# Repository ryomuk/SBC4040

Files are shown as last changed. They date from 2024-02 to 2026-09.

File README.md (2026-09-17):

# SBC4040
Single Board Computer using Intel 4040

This document is written mostly in Japanese.
If necessary, please use a translation service such as DeepL (I recommend this) or Google.

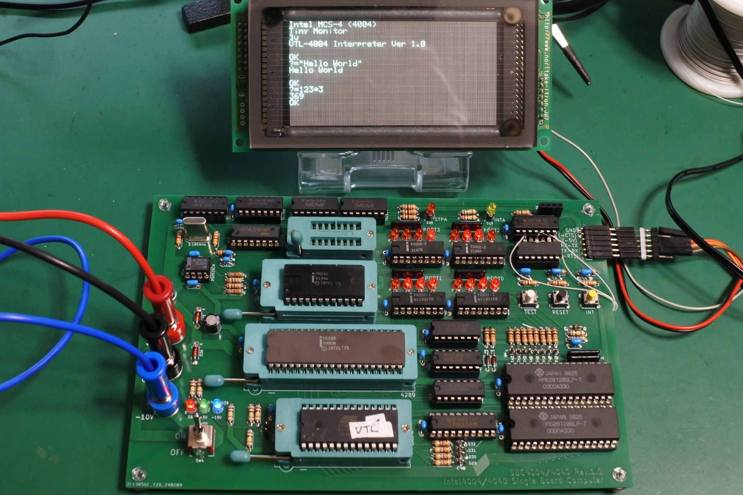
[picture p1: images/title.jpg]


## 概要
CPUにIntel 4040を採用したシングルボードコンピュータです．4004実験用ボードをベースにして作りました．4004版と完全上位互換なはず．4040の代わりに4004も載せられるようにしてあります．(絶対に同時には搭載しないこと!)

4040にすることによって追加された機能は下記の通りです．

- ROM領域が4KBから8KBに増加
- サブルーチンコールが3段から7段に増加
- PMR命令により，プログラム領域のRAMを直接読めるようになったはず(未確認)
- 割り込み機能
- ステップ実行は使い道が無さそうなので端子だけ出して未実装

## ToDo
- 割り込み機能の動作確認
- 拡張ROM領域(CMROM1)の動作確認
- PMR命令の動作確認
- モニタプログラム，VTL, 8080エミュレータ等を4040用にリライト

## ブログ
関連する情報が書いてあるかも．
- [Intel 4004関連記事のまとめ](https://note.com/ryomuk/m/m2f55e2a1f586)

## 動画
Youtubeで関連動画を公開しています．
- https://www.youtube.com/@ryomukai/videos

## 参考にした文献，サイト
### データシート
- http://www.bitsavers.org/components/intel/
- https://www.intel-vintage.info/intelmcs.htm

### ソフトウェア開発環境
- [The Macroassembler AS](http://john.ccac.rwth-aachen.de:8000/as/)

## 更新履歴
- 2024/2/22: 初版公開

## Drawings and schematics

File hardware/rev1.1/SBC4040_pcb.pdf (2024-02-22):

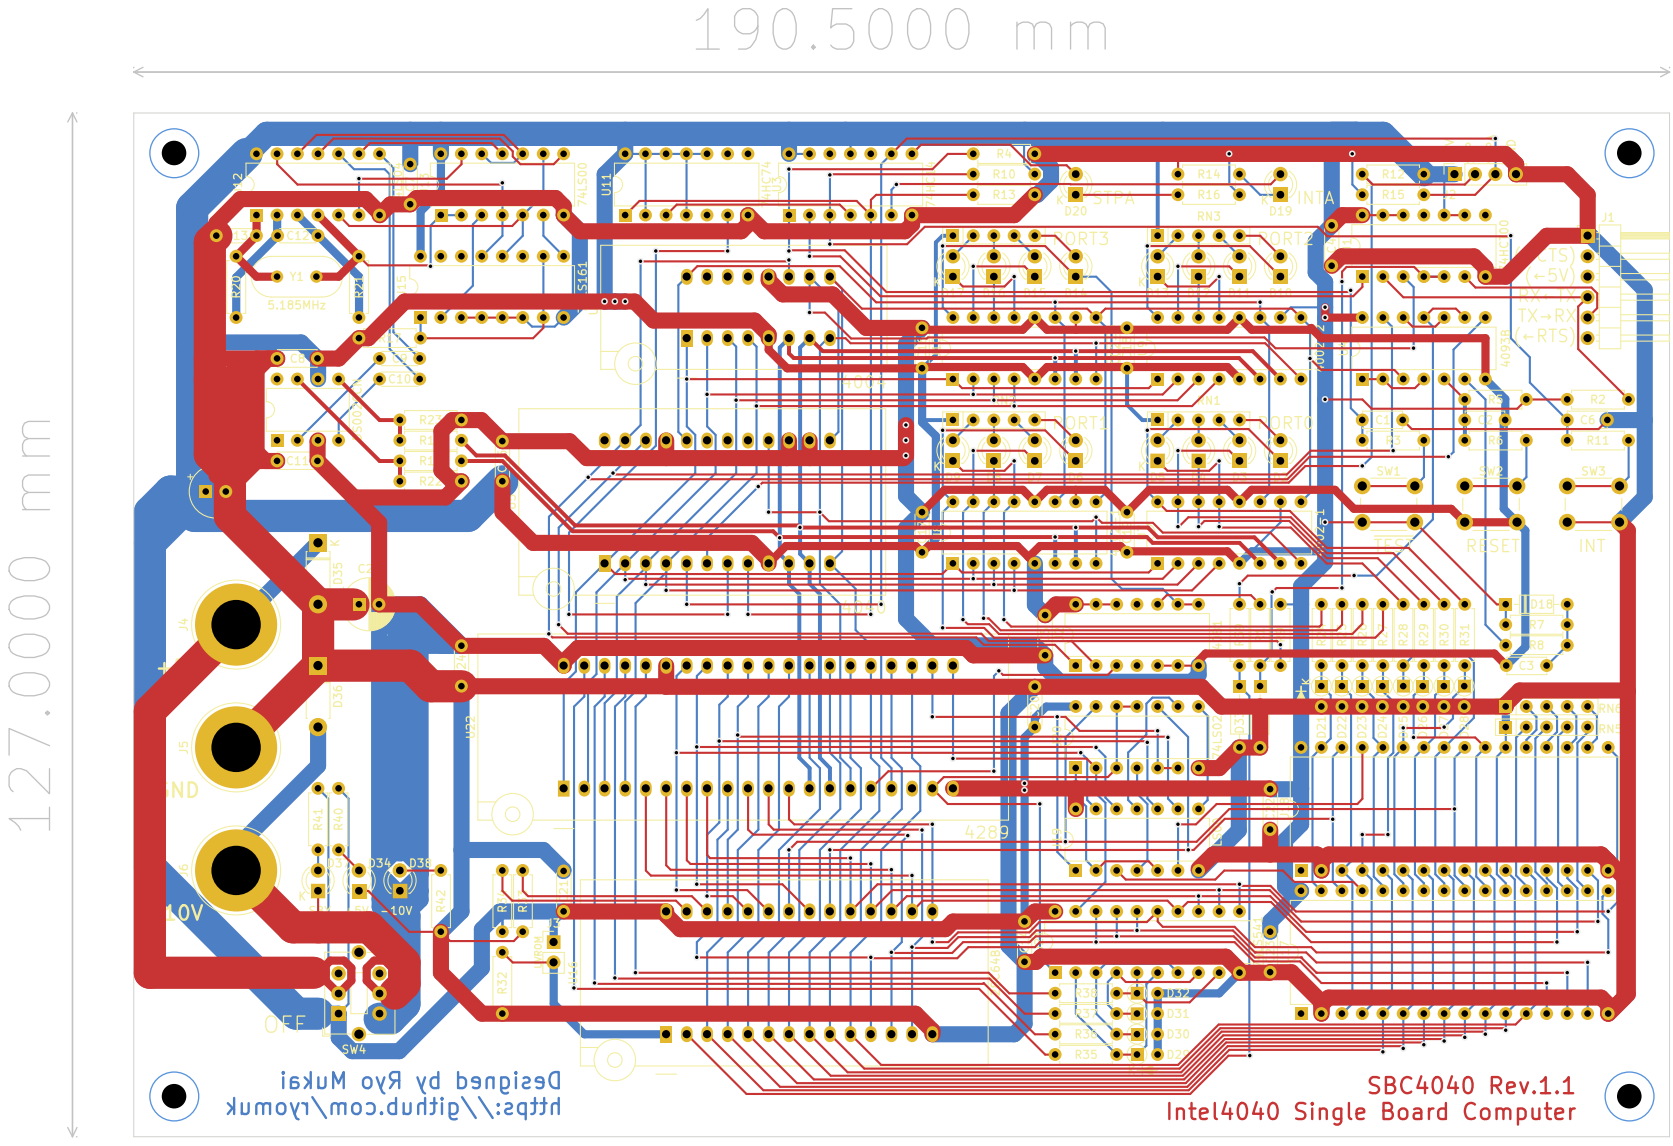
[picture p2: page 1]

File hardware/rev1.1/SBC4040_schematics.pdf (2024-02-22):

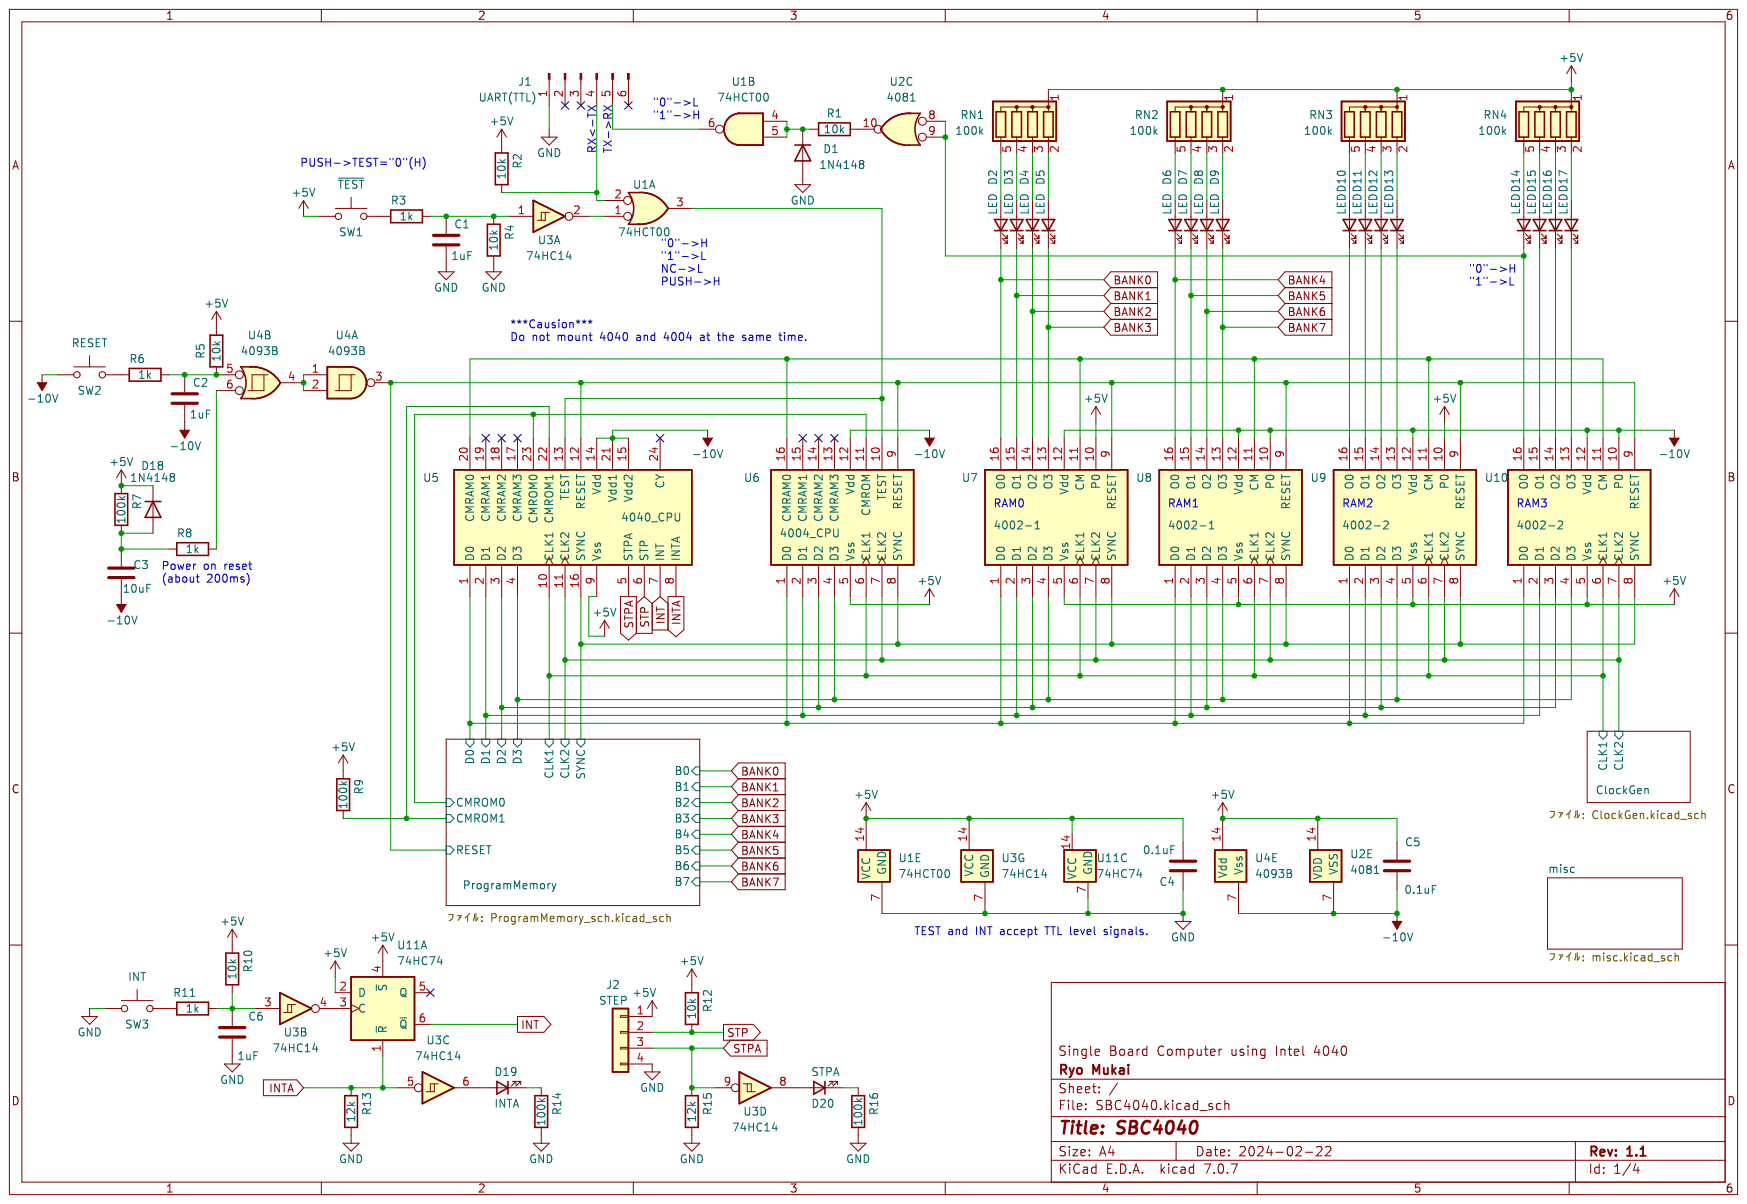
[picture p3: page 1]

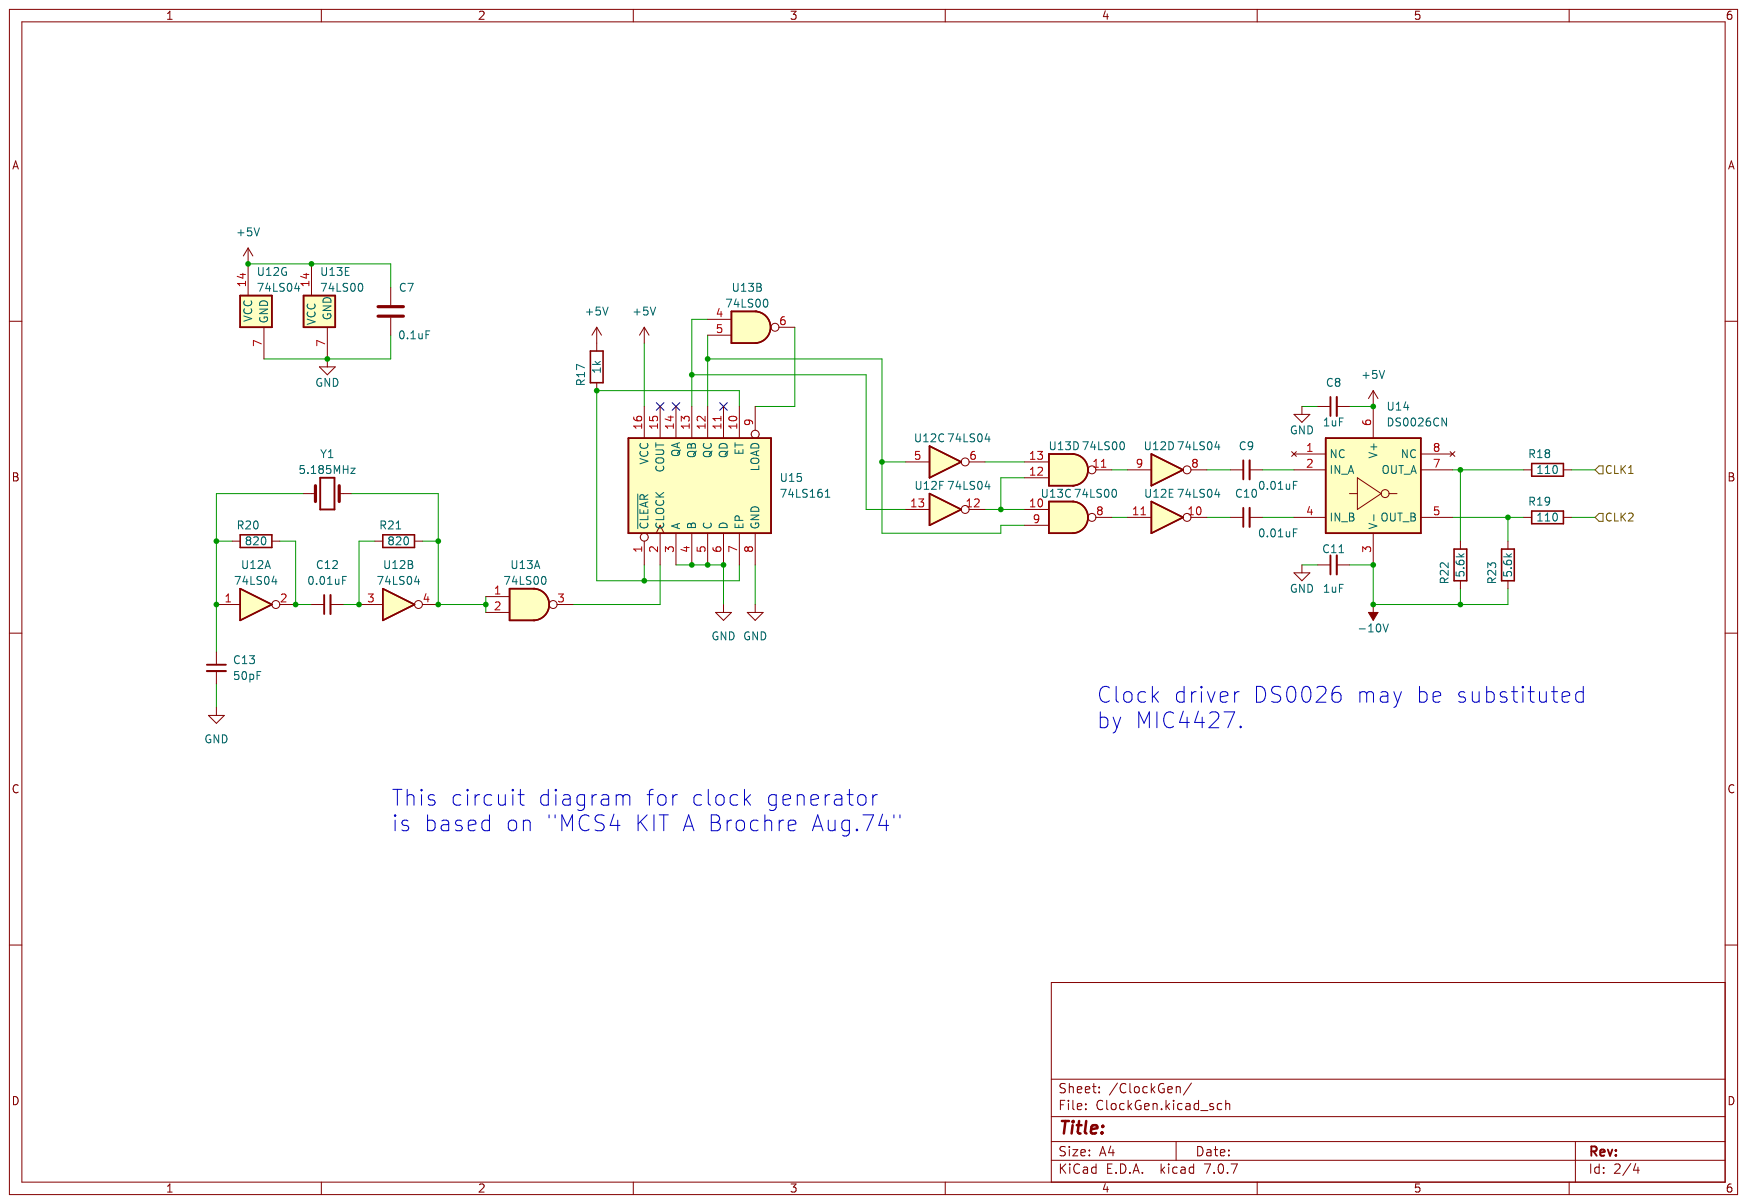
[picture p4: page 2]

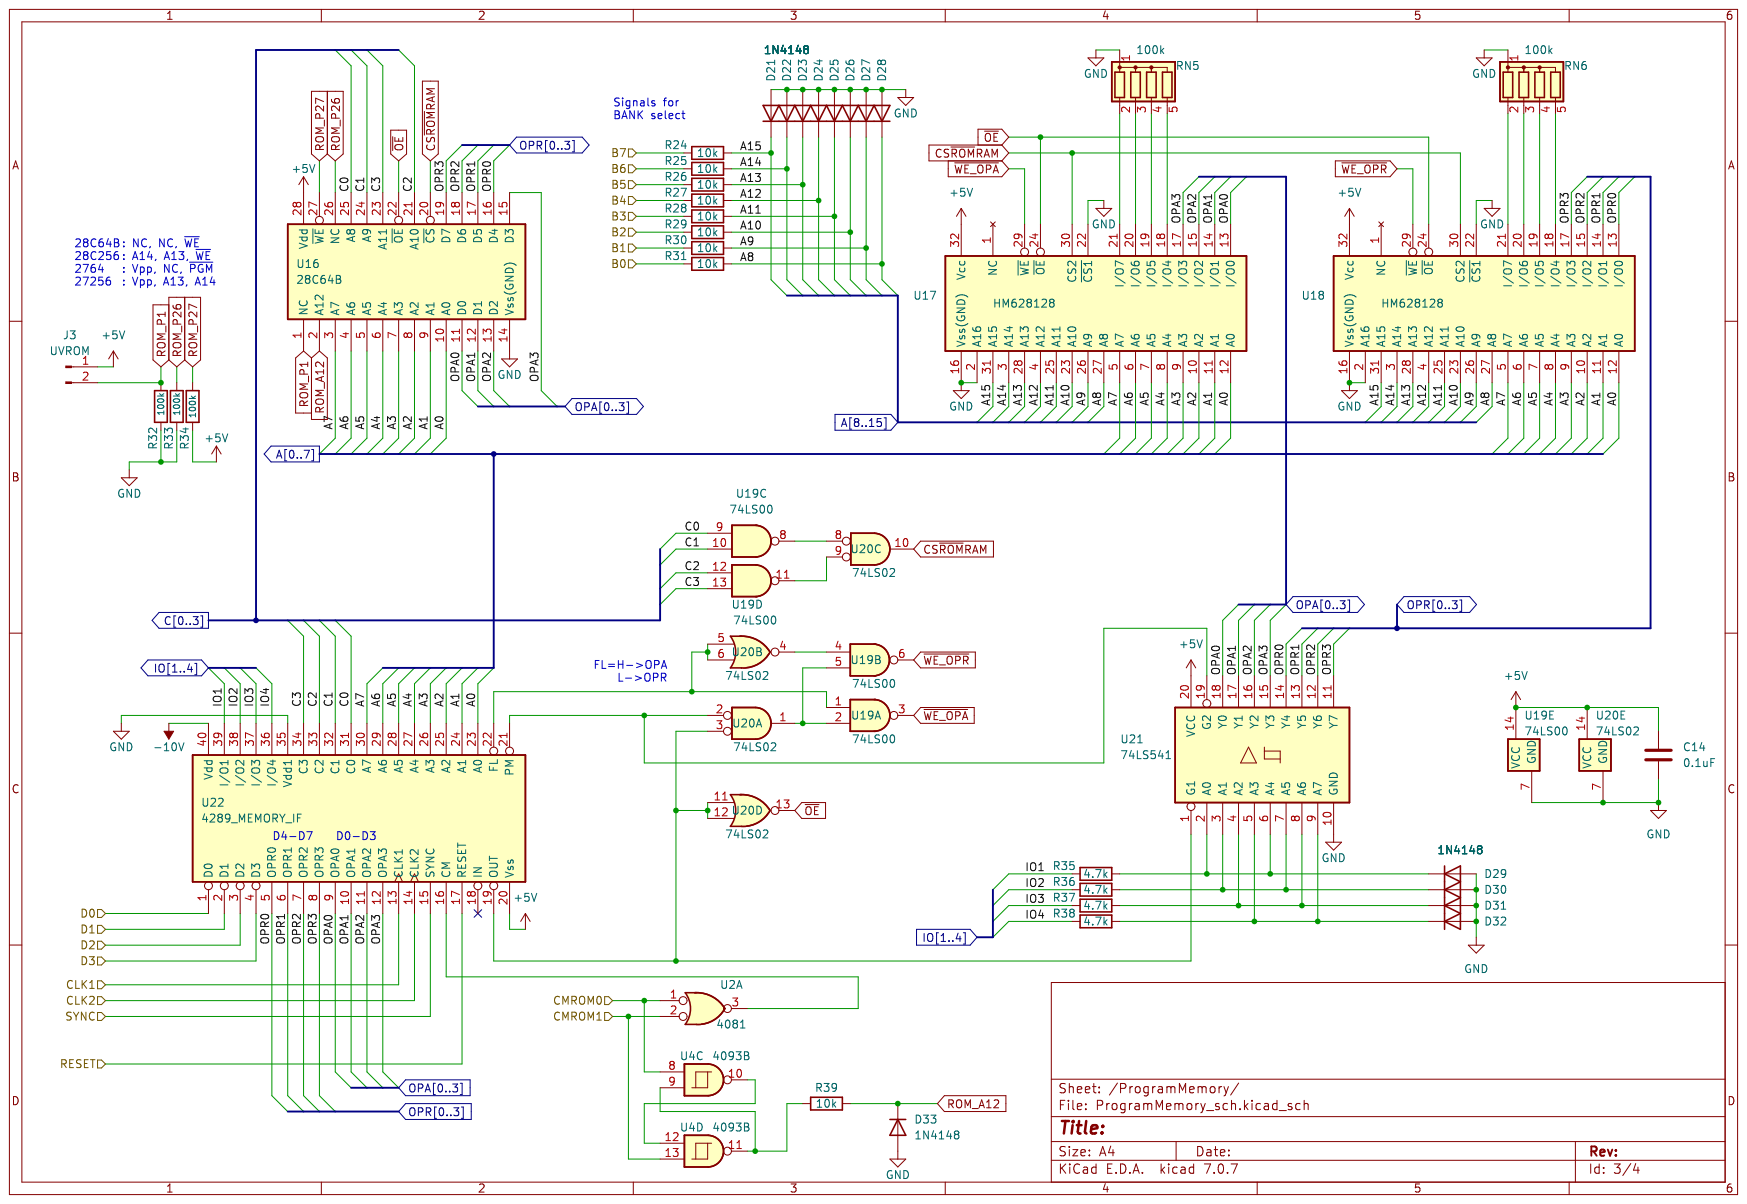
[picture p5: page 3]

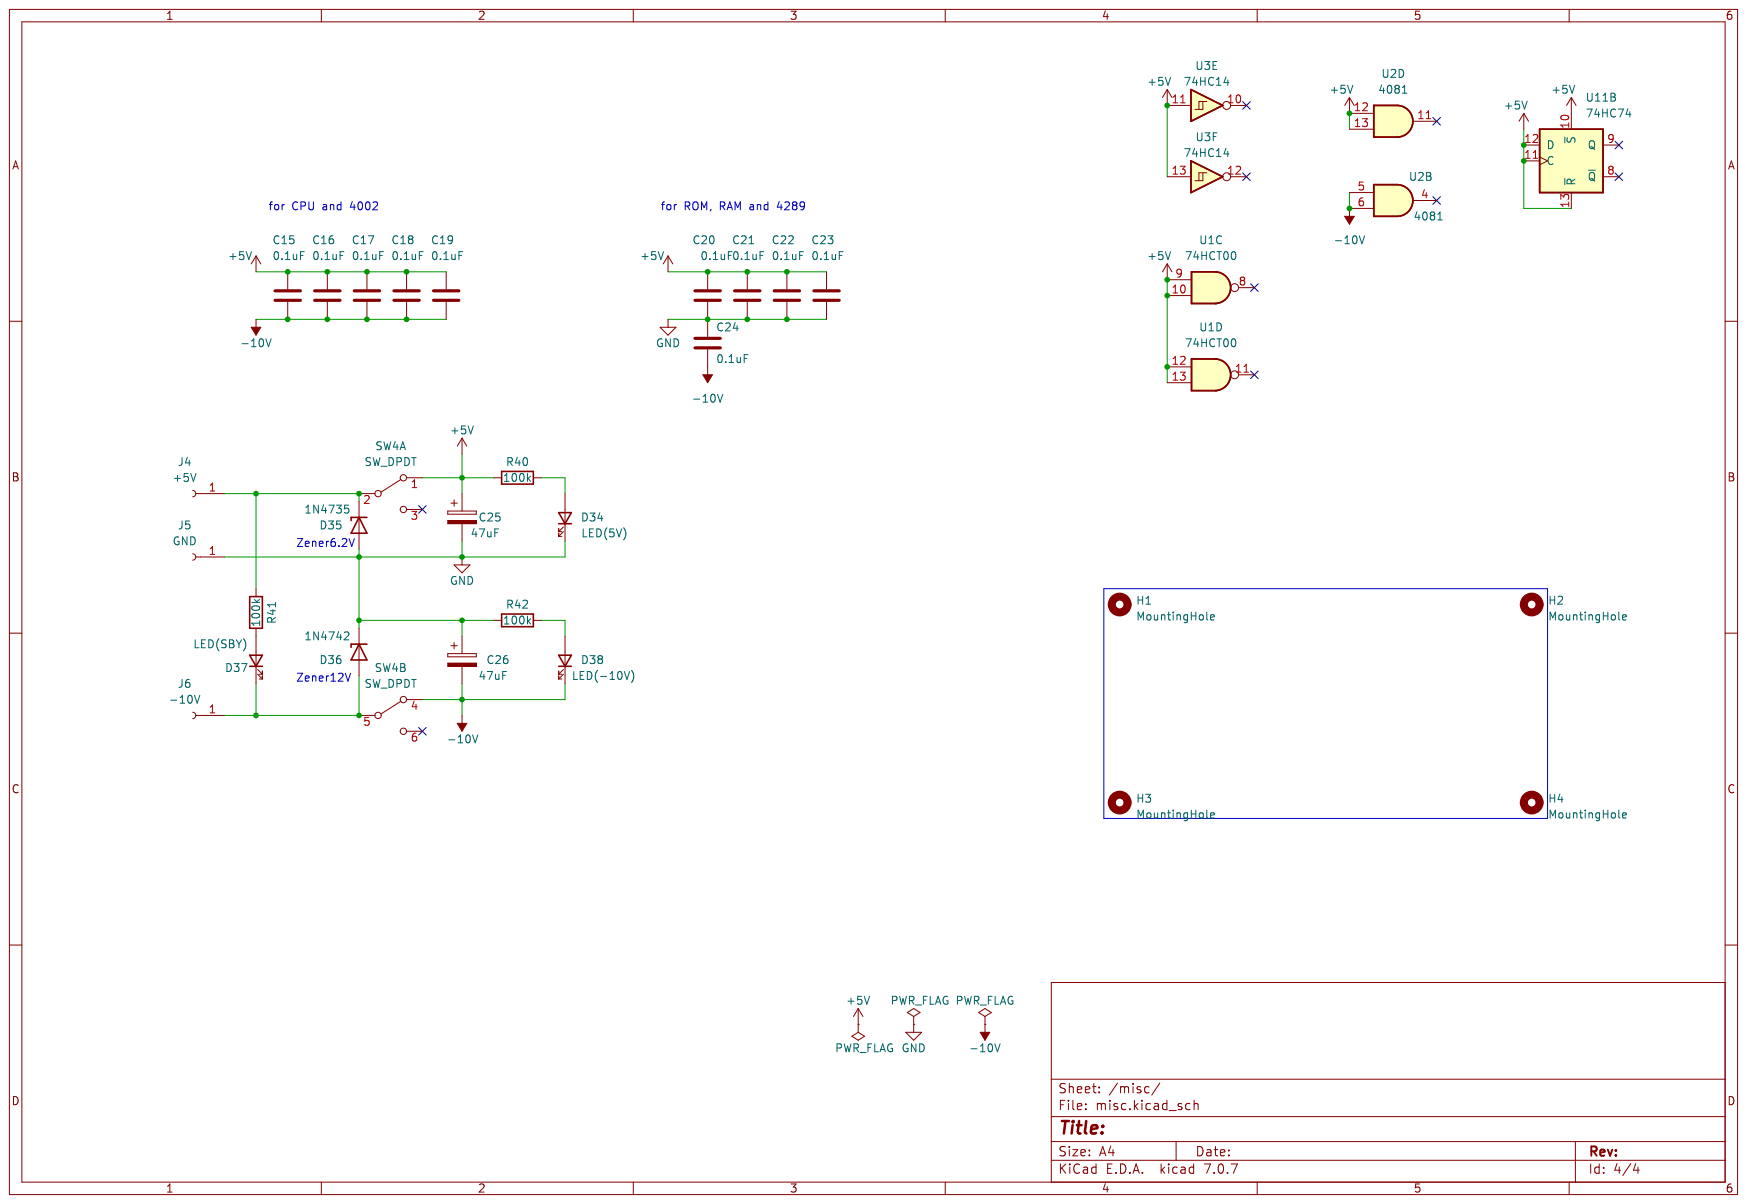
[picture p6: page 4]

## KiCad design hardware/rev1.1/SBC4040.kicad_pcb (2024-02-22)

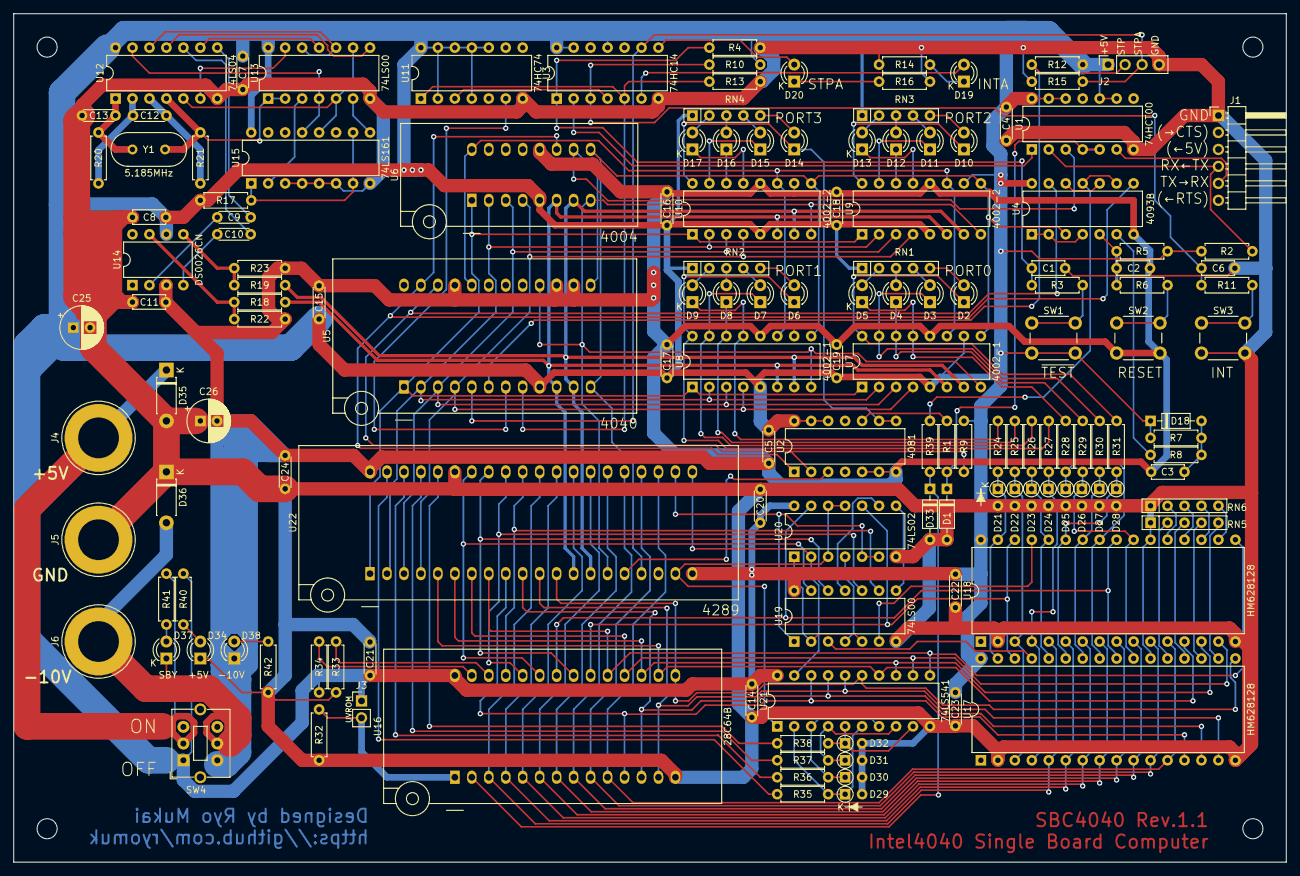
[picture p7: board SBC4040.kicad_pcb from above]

Board: 2 copper layers, 190.5 x 127.0 mm, 149 parts (0 on the bottom side), 156 nets.

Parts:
C1, C2, C6, C8, C11: 1uF; C_Disc_D4.7mm_W2.5mm_P5.00mm
C3: 10uF; C_Disc_D4.7mm_W2.5mm_P5.00mm
C4, C5, C7, C14, C15, C16, C17, C18, C19, C20, C21, C22, C23, C24: 0.1uF; C_Disc_D4.3mm_W1.9mm_P5.00mm
C9, C10, C12: 0.01uF; C_Disc_D4.3mm_W1.9mm_P5.00mm
C13: 50pF; C_Disc_D4.3mm_W1.9mm_P5.00mm
C25, C26: 47uF; CP_Radial_D6.3mm_P2.50mm
D1, D18, D33: 1N4148; D_DO-35_SOD27_P7.62mm_Horizontal
D2, D3, D4, D5, D6, D7, D8, D9, D10, D11, D12, D13, D14, D15, D16, D17: LED; LED_D3.0mm
D19: INTA; LED_D3.0mm
D20: STPA; LED_D3.0mm
D21, D22, D23, D24, D25, D26, D27, D28, D29, D30, D31, D32: 1N4148; D_DO-35_SOD27_P2.54mm_Vertical_AnodeUp
D34: LED(5V); LED_D3.0mm
D35: 1N4735; D_DO-41_SOD81_P7.62mm_Horizontal
D36: 1N4742; D_DO-41_SOD81_P7.62mm_Horizontal
D37: LED(SBY); LED_D3.0mm
D38: LED(-10V); LED_D3.0mm
H1, H2, H3, H4: MountingHole; MountingHole_3mm
J1: UART(TTL); PinHeader_1x06_P2.54mm_Horizontal
J2: STEP; PinSocket_1x04_P2.54mm_Vertical
J3: UVROM; PinHeader_1x02_P2.54mm_Vertical
J4: +5V; Banana_Jack_1Pin
J5: GND; Banana_Jack_1Pin
J6: -10V; Banana_Jack_1Pin
R1, R2, R4, R5, R10, R12, R24, R25, R26, R27, R28, R29, R30, R31, R39: 10k; R_Axial_DIN0207_L6.3mm_D2.5mm_P7.62mm_Horizontal
R3, R6, R8, R11, R17: 1k; R_Axial_DIN0207_L6.3mm_D2.5mm_P7.62mm_Horizontal
R7, R9, R14, R16, R32, R33, R34, R40, R41, R42: 100k; R_Axial_DIN0207_L6.3mm_D2.5mm_P7.62mm_Horizontal
R13, R15: 12k; R_Axial_DIN0207_L6.3mm_D2.5mm_P7.62mm_Horizontal
R18, R19: 110; R_Axial_DIN0207_L6.3mm_D2.5mm_P7.62mm_Horizontal
R20, R21: 820; R_Axial_DIN0207_L6.3mm_D2.5mm_P7.62mm_Horizontal
R22, R23: 5.6k; R_Axial_DIN0207_L6.3mm_D2.5mm_P7.62mm_Horizontal
R35, R36, R37, R38: 4.7k; R_Axial_DIN0207_L6.3mm_D2.5mm_P7.62mm_Horizontal
RN1, RN2, RN3, RN4, RN5, RN6: 100k; R_Array_SIP5
SW1: ~{TEST}; SW_PUSH_6mm_H4.3mm
SW2: RESET; SW_PUSH_6mm_H4.3mm
SW3: INT; SW_PUSH_6mm_H4.3mm
SW4: SW_DPDT; SW_DPDT_Toggle_with_mount
U1: 74HCT00; DIP-14_W7.62mm
U2: 4081; DIP-14_W7.62mm
U3: 74HC14; DIP-14_W7.62mm
U4: 4093B; DIP-14_W7.62mm
U5: 4040_CPU; DIP_Socket-24_W11.9_W12.7_W15.24_W17.78_W18.5_3M_224-1275-0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
U6: 4004_CPU; DIP_Socket-16_W4.3_W5.08_W7.62_W10.16_W10.9_3M_216-3340-00-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
U7, U8: 4002-1; DIP-16_W7.62mm
U9, U10: 4002-2; DIP-16_W7.62mm
U11: 74HC74; DIP-14_W7.62mm
U12: 74LS04; DIP-14_W7.62mm
U13, U19: 74LS00; DIP-14_W7.62mm
U14: DS0026CN; DIP-8_W7.62mm
U15: 74LS161; DIP-16_W7.62mm
U16: 28C64B; DIP_Socket-28_W11.9_W12.7_W15.24_W17.78_W18.5_3M_228-1277-0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
U17, U18: HM628128; DIP-32_W15.24mm
U20: 74LS02; DIP-14_W7.62mm
U21: 74LS541; DIP-20_W7.62mm
U22: 4289_MEMORY_IF; DIP_Socket-40_W11.9_W12.7_W15.24_W17.78_W18.5_3M_240-1280-0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
Y1: 5.185MHz; Crystal_HC49-U_Vertical

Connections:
+5V: C4.1, C5.2, C7.1, C8.2, C14.1, C15.1, C16.1, C17.1, C18.1, C19.1, C20.1, C21.1, C22.1, C23.1, C25.1, D18.1 (K), J2.1, J3.1, R2.1, R5.2, R7.1, R9.1, R10.1, R12.1, R17.2, R34.2, R40.1, RN1.1 (common), RN2.1 (common), RN3.1 (common), RN4.1 (common), SW1.1, SW4.1 (A), U1.9, U1.10, U1.12, U1.13, U1.14 (VCC), U2.12, U2.13, U2.14 (VDD), U3.11, U3.13, U3.14 (VCC), U4.14 (Vdd), U5.9 (Vss), U6.5 (Vss), U7.5 (Vss), U7.10 (P0), U8.5 (Vss), U9.5 (Vss), U9.10 (P0), U10.5 (Vss), U11.2 (D), U11.4 (~S), U11.10 (~S), U11.11 (C), U11.12 (D), U11.13 (~R), U11.14 (VCC), U12.14 (VCC), U13.14 (VCC), U14.6 (V+), U15.16 (VCC), U16.28 (Vdd), U17.32 (Vcc), U18.32 (Vcc), U19.14 (VCC), U20.14 (VCC), U21.20 (VCC), U22.20 (Vss)
-10V: C2.2, C3.2, C5.1, C11.2, C15.2, C16.2, C17.2, C18.2, C19.2, C24.2, C26.2, D38.1 (K), R22.1, R23.1, SW2.1, SW4.4 (A), U2.5, U2.6, U2.7 (VSS), U4.7 (Vss), U5.14 (Vdd), U5.15 (Vdd2), U5.21 (Vdd1), U6.12 (Vdd), U7.12 (Vdd), U8.10 (P0), U8.12 (Vdd), U9.12 (Vdd), U10.10 (P0), U10.12 (Vdd), U14.3 (V-), U22.40 (Vdd)
/ClockGen/CLK1: R18.2, U5.10 (CLK1), U6.6 (CLK1), U7.6 (CLK1), U8.6 (CLK1), U9.6 (CLK1), U10.6 (CLK1), U22.13 (CLK1)
/ClockGen/CLK2: R19.2, U5.11 (CLK2), U6.7 (CLK2), U7.7 (CLK2), U8.7 (CLK2), U9.7 (CLK2), U10.7 (CLK2), U22.14 (CLK2)
/ProgramMemory/CMROM0: U2.1, U4.8, U5.23 (CMROM0), U6.11 (CMROM)
/ProgramMemory/CMROM1: R9.2, U2.2, U4.13, U5.22 (CMROM1)
/ProgramMemory/D0: U5.1 (D0), U6.1 (D0), U7.1 (D0), U8.1 (D0), U9.1 (D0), U10.1 (D0), U22.1 (D0)
/ProgramMemory/D1: U5.2 (D1), U6.2 (D1), U7.2 (D1), U8.2 (D1), U9.2 (D1), U10.2 (D1), U22.2 (D1)
/ProgramMemory/D2: U5.3 (D2), U6.3 (D2), U7.3 (D2), U8.3 (D2), U9.3 (D2), U10.3 (D2), U22.3 (D2)
/ProgramMemory/D3: U5.4 (D3), U6.4 (D3), U7.4 (D3), U8.4 (D3), U9.4 (D3), U10.4 (D3), U22.4 (D3)
/ProgramMemory/RESET: U4.3, U5.12 (RESET), U6.9 (RESET), U7.9 (RESET), U8.9 (RESET), U9.9 (RESET), U10.9 (RESET), U22.17 (RESET)
/ProgramMemory/SYNC: U5.16 (SYNC), U6.8 (SYNC), U7.8 (SYNC), U8.8 (SYNC), U9.8 (SYNC), U10.8 (SYNC), U22.15 (SYNC)
A0: U16.10 (A0), U17.12 (A0), U18.12 (A0), U22.23 (A0)
A1: U16.9 (A1), U17.11 (A1), U18.11 (A1), U22.24 (A1)
A2: U16.8 (A2), U17.10 (A2), U18.10 (A2), U22.25 (A2)
A3: U16.7 (A3), U17.9 (A3), U18.9 (A3), U22.26 (A3)
A4: U16.6 (A4), U17.8 (A4), U18.8 (A4), U22.27 (A4)
A5: U16.5 (A5), U17.7 (A5), U18.7 (A5), U22.28 (A5)
A6: U16.4 (A6), U17.6 (A6), U18.6 (A6), U22.29 (A6)
A7: U16.3 (A7), U17.5 (A7), U18.5 (A7), U22.30 (A7)
A8: D28.1 (K), R31.2, U17.27 (A8), U18.27 (A8)
A9: D27.1 (K), R30.2, U17.26 (A9), U18.26 (A9)
A10: D26.1 (K), R29.2, U17.23 (A10), U18.23 (A10)
A11: D25.1 (K), R28.2, U17.25 (A11), U18.25 (A11)
A12: D24.1 (K), R27.2, U17.4 (A12), U18.4 (A12)
A13: D23.1 (K), R26.2, U17.28 (A13), U18.28 (A13)
A14: D22.1 (K), R25.2, U17.3 (A14), U18.3 (A14)
A15: D21.1 (K), R24.2, U17.31 (A15), U18.31 (A15)
BANK0: D2.1 (K), R31.1, U7.16 (O0)
BANK1: D3.1 (K), R30.1, U7.15 (O1)
BANK2: D4.1 (K), R29.1, U7.14 (O2)
BANK3: D5.1 (K), R28.1, U7.13 (O3)
BANK4: D6.1 (K), R27.1, U8.16 (O0)
BANK5: D7.1 (K), R26.1, U8.15 (O1)
BANK6: D8.1 (K), R25.1, U8.14 (O2)
BANK7: D9.1 (K), R24.1, U8.13 (O3)
C0: U16.25 (A8), U19.9, U22.31 (C0)
C1: U16.24 (A9), U19.10, U22.32 (C1)
C2: U16.21 (A10), U19.12, U22.33 (C2)
C3: U16.23 (A11), U19.13, U22.34 (C3)
CS~ROMRAM: U16.20 (~CS), U17.30 (CS2), U18.30 (CS2), U20.10
GND: C1.2, C4.2, C6.2, C7.2, C8.1, C11.1, C13.2, C14.2, C20.2, C21.2, C22.2, C23.2, C24.1, C25.2, C26.1, D1.2 (A), D21.2 (A), D22.2 (A), D23.2 (A), D24.2 (A), D25.2 (A), D26.2 (A), D27.2 (A), D28.2 (A), D29.2 (A), D30.2 (A), D31.2 (A), D32.2 (A), D33.2 (A), D34.1 (K), D35.2 (A), D36.1 (K), J1.1, J2.4, J5.1, R4.2, R13.2, R14.2, R15.2, R16.2, R32.1, R33.1, R42.1, RN5.1 (common), RN6.1 (common), SW3.1, U1.7 (GND), U3.7 (GND), U11.7 (GND), U12.7 (GND), U13.7 (GND), U15.3 (A), U15.4 (B), U15.5 (C), U15.6 (D), U15.8 (GND), U16.14 (Vss(GND)), U17.2 (A16), U17.16 (Vss(GND)), U17.22 (~CS1), U18.2 (A16), U18.16 (Vss(GND)), U18.22 (~CS1), U19.7 (GND), U20.7 (GND), U21.10 (GND), U22.35 (Vdd1)
INT: U5.7 (INT), U11.6 (~Q)
INTA: R13.1, U3.5, U5.8 (INTA), U11.1 (~R)
IO1: R35.1, U22.39 (I/O1)
IO2: R36.1, U22.38 (I/O2)
IO3: R37.1, U22.37 (I/O3)
IO4: R38.1, U22.36 (I/O4)
unnamed: C1.1, R3.2, R4.1, U3.1
unnamed: C2.1, R5.1, R6.2, U4.5
unnamed: C6.1, R10.2, R11.2, U3.3
unnamed: C9.1, U12.8
unnamed: C10.1, U12.10
unnamed: C12.1, R20.2, U12.2
unnamed: C12.2, R21.1, U12.3
unnamed: C13.1, R20.1, U12.1, Y1.1
unnamed: D1.1 (K), R1.1, U1.4, U1.5
unnamed: D2.2 (A), RN1.5 (R4)
unnamed: D3.2 (A), RN1.4 (R3)
unnamed: D4.2 (A), RN1.3 (R2)
unnamed: D5.2 (A), RN1.2 (R1)
unnamed: D6.2 (A), RN2.5 (R4)
unnamed: D7.2 (A), RN2.4 (R3)
unnamed: D8.2 (A), RN2.3 (R2)
unnamed: D9.2 (A), RN2.2 (R1)
unnamed: D10.2 (A), RN3.5 (R4)
unnamed: D10.1 (K), U9.16 (O0)
unnamed: D11.2 (A), RN3.4 (R3)
unnamed: D11.1 (K), U9.15 (O1)
unnamed: D12.2 (A), RN3.3 (R2)
unnamed: D12.1 (K), U9.14 (O2)
unnamed: D13.2 (A), RN3.2 (R1)
unnamed: D13.1 (K), U9.13 (O3)
unnamed: D14.2 (A), RN4.5 (R4)
unnamed: D14.1 (K), U2.8, U2.9, U10.16 (O0)
unnamed: D15.2 (A), RN4.4 (R3)
unnamed: D15.1 (K), U10.15 (O1)
unnamed: D16.2 (A), RN4.3 (R2)
unnamed: D16.1 (K), U10.14 (O2)
unnamed: D17.2 (A), RN4.2 (R1)
unnamed: D17.1 (K), U10.13 (O3)
unnamed: C3.1, D18.2 (A), R7.2, R8.1
unnamed: D19.2 (A), U3.6
unnamed: D19.1 (K), R14.1
unnamed: D20.2 (A), U3.8
unnamed: D20.1 (K), R16.1
unnamed: D29.1 (K), R35.2, U21.2 (A0), U21.6 (A4)
unnamed: D30.1 (K), R36.2, U21.3 (A1), U21.7 (A5)
unnamed: D31.1 (K), R37.2, U21.4 (A2), U21.8 (A6)
unnamed: D32.1 (K), R38.2, U21.5 (A3), U21.9 (A7)
unnamed: D34.2 (A), R40.2
unnamed: D35.1 (K), J4.1, R41.1, SW4.2 (B)
unnamed: D36.2 (A), D37.1 (K), J6.1, SW4.5 (B)
unnamed: D37.2 (A), R41.2
unnamed: D38.2 (A), R42.2
unnamed: J1.4, R2.2, U1.2
unnamed: J1.5, U1.6
unnamed: R1.2, U2.10
unnamed: R3.1, SW1.2
unnamed: R6.1, SW2.2
unnamed: R8.2, U4.6
unnamed: R11.1, SW3.2
unnamed: R21.2, U12.4, U13.1, U13.2, Y1.2
unnamed: R39.1, U4.9, U4.11
unnamed: RN5.2 (R1), U17.21 (I/O7)
unnamed: RN5.3 (R2), U17.20 (I/O6)
unnamed: RN5.4 (R3), U17.19 (I/O5)
unnamed: RN5.5 (R4), U17.18 (I/O4)
unnamed: RN6.2 (R1), U18.21 (I/O7)
unnamed: RN6.3 (R2), U18.20 (I/O6)
unnamed: RN6.4 (R3), U18.19 (I/O5)
unnamed: RN6.5 (R4), U18.18 (I/O4)
unnamed: U1.1, U3.2
unnamed: U4.1, U4.2, U4.4
unnamed: U4.10, U4.12
unnamed: U1.3, U5.13 (TEST), U6.10 (TEST)
unnamed: U5.20 (CMRAM0), U6.16 (CMRAM0), U7.11 (CM), U8.11 (CM), U9.11 (CM), U10.11 (CM)
unnamed: U3.4, U11.3 (C)
unnamed: U12.6, U13.13
unnamed: U12.9, U13.11
unnamed: U12.11, U13.8
unnamed: U12.12, U13.10, U13.12
unnamed: C9.2, U14.2 (IN_A)
unnamed: C10.2, U14.4 (IN_B)
unnamed: R18.1, R22.2, U14.7 (OUT_A)
unnamed: R19.1, R23.2, U14.5 (OUT_B)
unnamed: U13.3, U15.2 (CLOCK)
unnamed: R17.1, U15.1 (~CLEAR), U15.7 (EP), U15.10 (ET)
unnamed: U13.6, U15.9 (LOAD)
unnamed: U12.13, U13.4, U15.13 (QB)
unnamed: U12.5, U13.5, U13.9, U15.12 (QC)
unnamed: U19.2, U19.5, U20.1
unnamed: U19.4, U20.4
unnamed: U19.8, U20.8
unnamed: U19.11, U20.9
unnamed: U20.3, U20.11, U20.12, U21.1 (G1), U22.19 (OUT)
unnamed: U20.2, U21.19 (G2), U22.21 (PM)
unnamed: U2.3, U22.16 (CM)
unnamed: U19.1, U20.5, U20.6, U22.22 (FL)
OPA0: U16.11 (D0), U17.13 (I/O0), U21.18 (Y0), U22.9 (OPA0)
OPA1: U16.12 (D1), U17.14 (I/O1), U21.17 (Y1), U22.10 (OPA1)
OPA2: U16.13 (D2), U17.15 (I/O2), U21.16 (Y2), U22.11 (OPA2)
OPA3: U16.15 (D3), U17.17 (I/O3), U21.15 (Y3), U22.12 (OPA3)
OPR0: U16.16 (D4), U18.13 (I/O0), U21.14 (Y4), U22.5 (OPR0)
OPR1: U16.17 (D5), U18.14 (I/O1), U21.13 (Y5), U22.6 (OPR1)
OPR2: U16.18 (D6), U18.15 (I/O2), U21.12 (Y6), U22.7 (OPR2)
OPR3: U16.19 (D7), U18.17 (I/O3), U21.11 (Y7), U22.8 (OPR3)
ROM_A12: D33.1 (K), R39.2, U16.2 (A12)
ROM_P1: J3.2, R32.2, U16.1 (NC)
ROM_P26: R33.2, U16.26 (NC)
ROM_P27: R34.1, U16.27 (~WE)
STP: J2.2, R12.2, U5.6 (STP)
STPA: J2.3, R15.1, U3.9, U5.5 (STPA)
~OE: U16.22 (~OE), U17.24 (~OE), U18.24 (~OE), U20.13
~WE_OPA: U17.29 (~WE), U19.3
~WE_OPR: U18.29 (~WE), U19.6
